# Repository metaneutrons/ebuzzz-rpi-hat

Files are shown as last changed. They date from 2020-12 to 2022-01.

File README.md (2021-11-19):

# eBuzzz adapter, an eBus to serial adapter

An eBus adapter, to convert eBus signal levels to serial level for a serial to USB converter (Works with CP2102)

# Manufacturing

Manufacturing in the `manufacturing` folder are made for JLCPCB, you may need to tweak them for other manufacturers.

# Software

The eBus protocol can be connected to with [ebusd](https://github.com/john30/ebusd). If you happen to use Home Assistant you can also connect ebusd to your Home Assistant.

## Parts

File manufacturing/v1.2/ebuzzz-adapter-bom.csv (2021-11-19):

Designator | Comment | Footprint | LCSC
C1 | 1u | Capacitor_SMD:C_0805_2012Metric | C28323
C2 | 1u | Capacitor_SMD:C_0805_2012Metric | C28323
C3 | 100n | Capacitor_SMD:C_0805_2012Metric | C49678
C4 | 1u | Capacitor_SMD:C_0805_2012Metric | C28323
C5 | 100n | Capacitor_SMD:C_0805_2012Metric | C49678
C6 | 4.7u | Capacitor_SMD:C_0805_2012Metric | C1779
D1 | RX green | LED_SMD:LED_0805_2012Metric | C2297
D2 | TX red | LED_SMD:LED_0805_2012Metric | C84256
D3 | 1SMB5924BY3G | Diode_SMD:D_SMA | C53166
D4 | ABS10 | Diode_SMD:Diode_Bridge_Diotec_ABS | C65028
D5 | power yellow | LED_SMD:LED_0805_2012Metric | C2296
D6 | 1N4148WS | Diode_SMD:D_SOD-323 | C57759
D7 | TPSP0503BAHTG | Package_TO_SOT_SMD:SOT-143 | C2682275
F1 | 1A | Fuse:Fuse_1206_3216Metric | C182308
Q1 | BC817-40 | Package_TO_SOT_SMD:SOT-23 | C181151
R3 | 1k | Resistor_SMD:R_0805_2012Metric | C17513
R4 | 470 | Resistor_SMD:R_0805_2012Metric | C17710
R5 | 2.2k | Resistor_SMD:R_0805_2012Metric | C17520
R6 | 470 | Resistor_SMD:R_0805_2012Metric | C17710
R7 | 470 | Resistor_SMD:R_0805_2012Metric | C17710
R8 | 470 | Resistor_SMD:R_0805_2012Metric | C17710
R9 | 10k | Resistor_SMD:R_0805_2012Metric | C17414
R10 | 220k | Resistor_SMD:R_0805_2012Metric | C17556
R11 | 18k | Resistor_SMD:R_0805_2012Metric | C17506
R12 | 15k | Resistor_SMD:R_0805_2012Metric | C17475
R13 | 100k | Resistor_SMD:R_0805_2012Metric | C17407
R14 | 22k | Resistor_SMD:R_0805_2012Metric | C17560
R15 | 10k | Resistor_SMD:R_0805_2012Metric | C17414
R16 | 120E | Resistor_SMD:R_0805_2012Metric | C17437
U1 | LTV-357T | Package_SO:SO-4_4.4x3.6mm_P2.54mm | C33068
U2 | LTV-357T | Package_SO:SO-4_4.4x3.6mm_P2.54mm | C33068
U3 | LM2903DT | Package_SO:SOIC-8_3.9x4.9mm_P1.27mm | C98194
U4 | LP2951-50DR | Package_SO:SOIC-8_3.9x4.9mm_P1.27mm | C109380
U5 | CP2104-F03-GM | Package_DFN_QFN:QFN-24-1EP_4x4mm_P0.5mm_EP2.6x2.6mm_ThermalVias | C430013
J4 | EBUS | Connector_Phoenix_MC:PhoenixContact_MC_1.5_2-G-3.81_1x02_P3.81mm_Horizontal | C69811
J1 | USB A | Connector_USB:USB_A_CNCTech_1001-011-01101_Horizontal | C319178

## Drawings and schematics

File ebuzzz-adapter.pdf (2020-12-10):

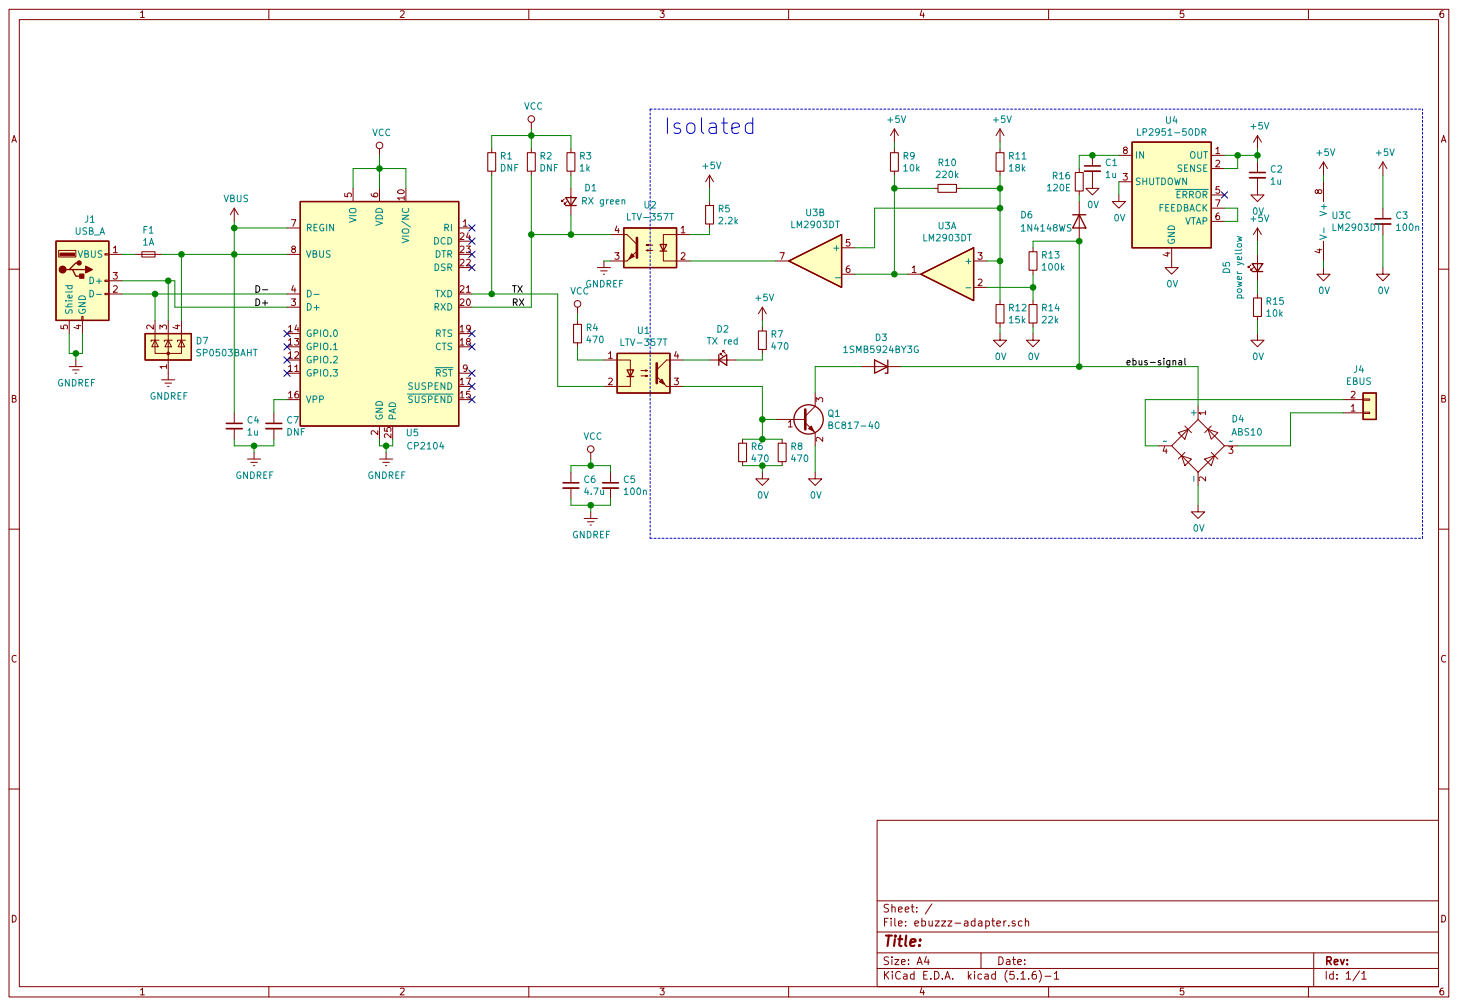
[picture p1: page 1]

4 D7SP0503BAHT OUT 1 SENSE 2 SHUTDOWN 3 GND

2 RXD 20 TXD 21 DSR 22 DTR 23 DCD 24 PAD 25 D+ 3 D- 4 VIO

File: ebuzzz-adapter.sch Sheet: /
Id: 1/1 Title:

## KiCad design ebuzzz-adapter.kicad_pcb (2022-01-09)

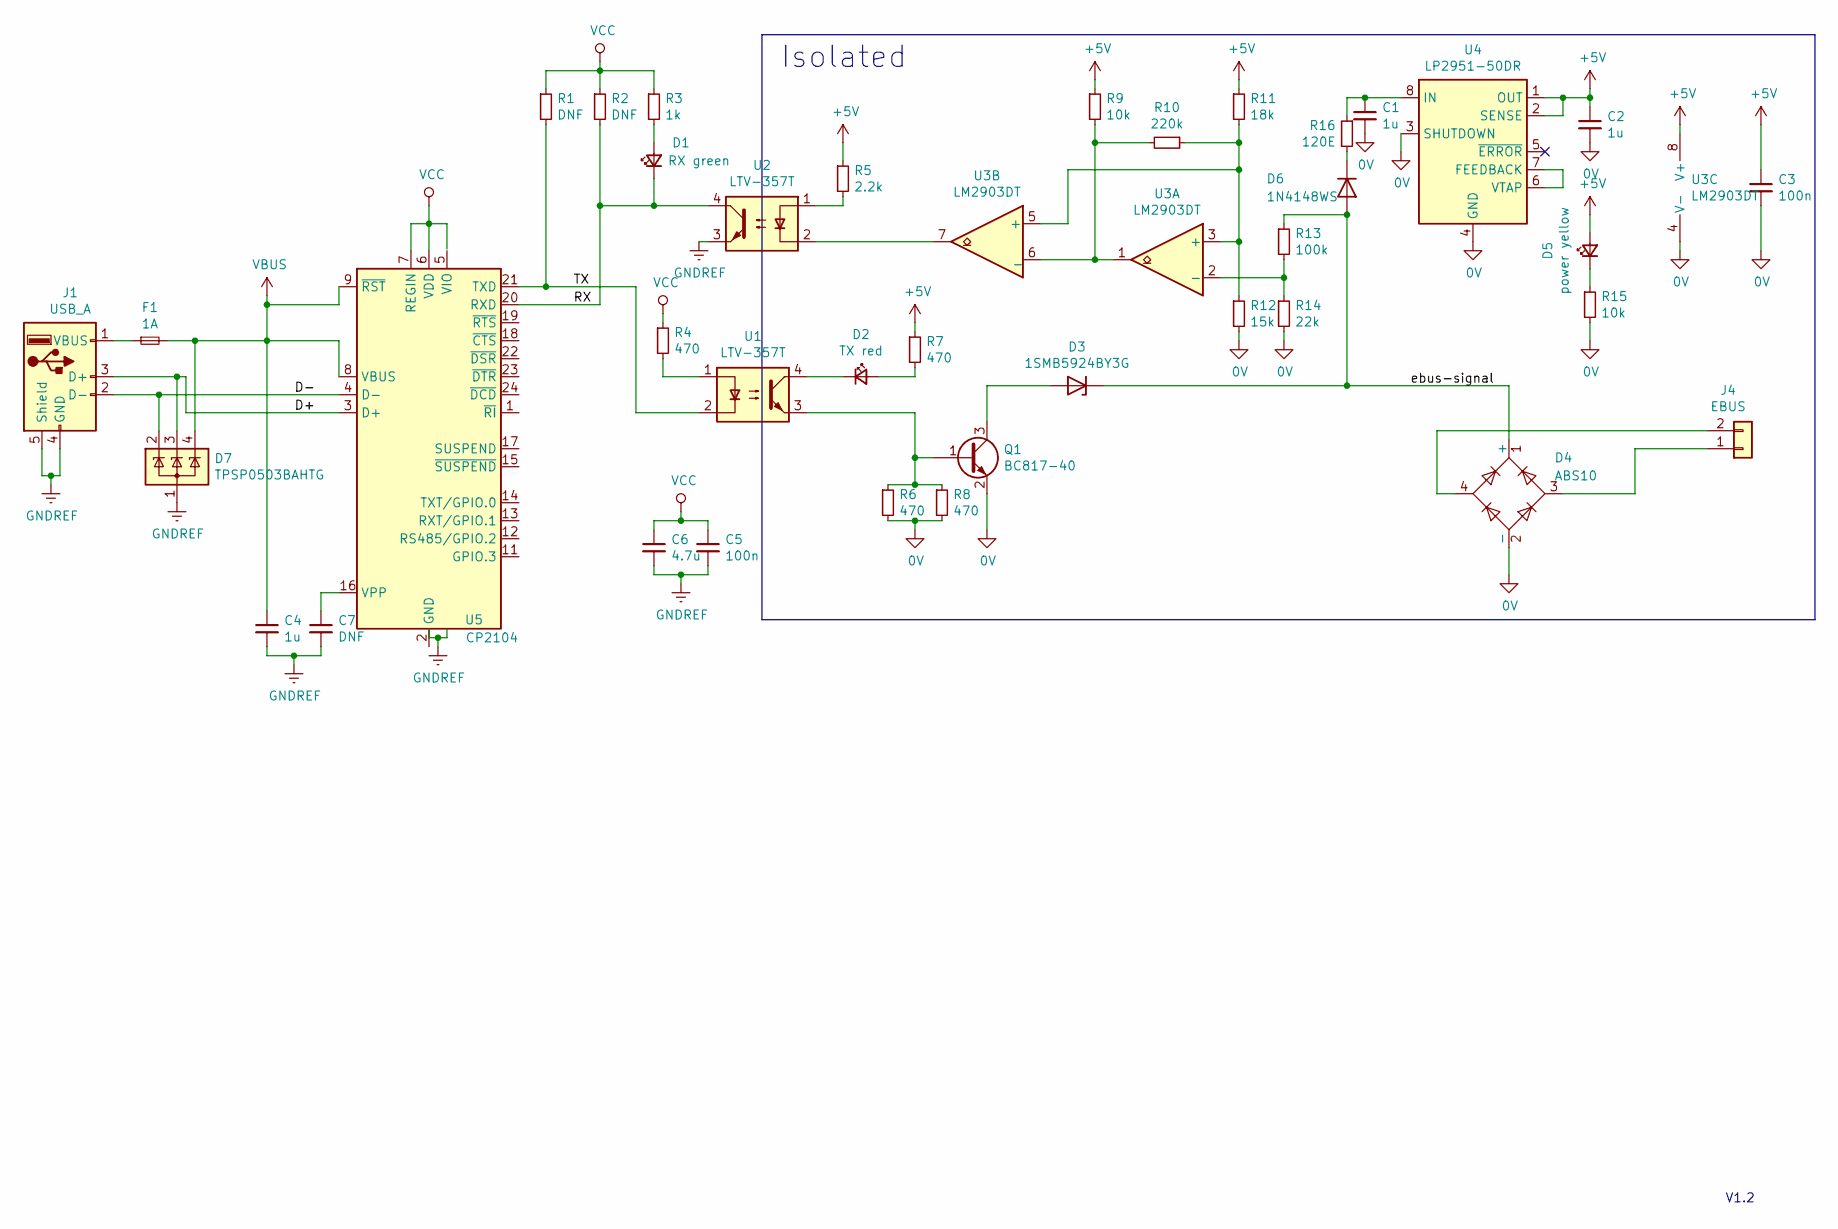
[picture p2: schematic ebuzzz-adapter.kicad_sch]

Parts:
C1, C2, C4: 1u; C_0805_2012Metric; LCSC C28323
C3, C5: 100n; C_0805_2012Metric; LCSC C49678
C6: 4.7u; C_0805_2012Metric; LCSC C1779
C7: DNF; C_0805_2012Metric
D1: RX green; LED_0805_2012Metric; LCSC C2297
D2: TX red; LED_0805_2012Metric; LCSC C84256
D3: 1SMB5924BY3G; D_SMA; Farnell 1611267
D4: ABS10; Diode_Bridge_Diotec_ABS; Farnell 3127182
D5: power yellow; LED_0805_2012Metric; LCSC C2296
D6: 1N4148WS; D_SOD-323; Farnell 2675148
D7: TPSP0503BAHTG; SOT-143; LCSC C2682275
F1: 1A; Fuse_1206_3216Metric; LCSC C182308
J1: USB_A; XKB_Connectivity_U217-041N-4BV81; LCSC C319178
J4: EBUS; PhoenixContact_MC_1,5_2-G-3.81_1x02_P3.81mm_Horizontal; LCSC C69811
Q1: BC817-40; SOT-23; Farnell 1798081
R1, R2: DNF; R_0805_2012Metric
R3: 1k; R_0805_2012Metric; LCSC C17513
R4, R6, R7, R8: 470; R_0805_2012Metric; LCSC C17710
R5: 2.2k; R_0805_2012Metric; LCSC C17520
R9, R15: 10k; R_0805_2012Metric; LCSC C17414
R10: 220k; R_0805_2012Metric; LCSC C17556
R11: 18k; R_0805_2012Metric; LCSC C17506
R12: 15k; R_0805_2012Metric; LCSC C17475
R13: 100k; R_0805_2012Metric; LCSC C17407
R14: 22k; R_0805_2012Metric; LCSC C17560
R16: 120E; R_0805_2012Metric; LCSC C17437
U1, U2: LTV-357T; SO-4_4.4x3.6mm_P2.54mm; LCSC C33068
U3: LM2903DT; SOIC-8_3.9x4.9mm_P1.27mm; Farnell 2382615
U4: LP2951-50DR; SOIC-8_3.9x4.9mm_P1.27mm; Farnell 1755065
U5: CP2104; QFN-24-1EP_4x4mm_P0.5mm_EP2.6x2.6mm_ThermalVias; LCSC C47742

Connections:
+5V: C2.1, C3.1, D5.2 (A), R5.1, R7.1, R9.1, R11.1, U3.8 (V+), U4.1 (OUT), U4.2 (SENSE)
/D+: D7.3 (K), J1.3 (D+), U5.3 (D+)
/D-: D7.2 (K), J1.2 (D-), U5.4 (D-)
/RX: D1.1 (K), R2.2, U2.4, U5.20 (RXD)
/TX: R1.2, U1.2, U5.21 (TXD)
/ebus-signal: D3.1 (K), D4.1 (+), D6.2 (A), R13.1
GND: C1.2, C2.2, C3.2, D4.2 (-), Q1.2 (E), R6.2, R8.2, R12.2, R14.2, R15.2, U3.4 (V-), U4.3 (SHUTDOWN), U4.4 (GND)
GNDREF: C4.2, C5.2, C6.2, C7.2, D7.1 (A), J1.4 (GND), J1.5 (Shield), U2.3
unnamed: C1.1, R16.1, U4.8 (IN)
unnamed: C7.1, U5.16 (VPP)
unnamed: D1.2 (A), R3.2
unnamed: D2.1 (K), U1.4
unnamed: D2.2 (A), R7.2
unnamed: D3.2 (A), Q1.3 (C)
unnamed: D4.3, J4.1
unnamed: D4.4, J4.2
unnamed: D5.1 (K), R15.1
unnamed: D6.1 (K), R16.2
unnamed: F1.1, J1.1 (VBUS)
unnamed: Q1.1 (B), R6.1, R8.1, U1.3
unnamed: R4.2, U1.1
unnamed: R5.2, U2.1
unnamed: R10.1, R11.2, R12.1, U3.3 (+), U3.5 (+)
unnamed: R9.2, R10.2, U3.1, U3.6 (_)
unnamed: R13.2, R14.1, U3.2 (-)
unnamed: U2.2, U3.7
unnamed: U4.6 (VTAP), U4.7 (FEEDBACK)
unnamed: U5.2 (GND), U5.25 (GND)
VBUS: C4.1, D7.4 (K), F1.2, U5.8 (VBUS), U5.9 (~RST)
VCC: C5.1, C6.1, R1.1, R2.1, R3.1, R4.1, U5.6 (VDD), U5.7 (REGIN)

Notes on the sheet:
Isolated
V1.2

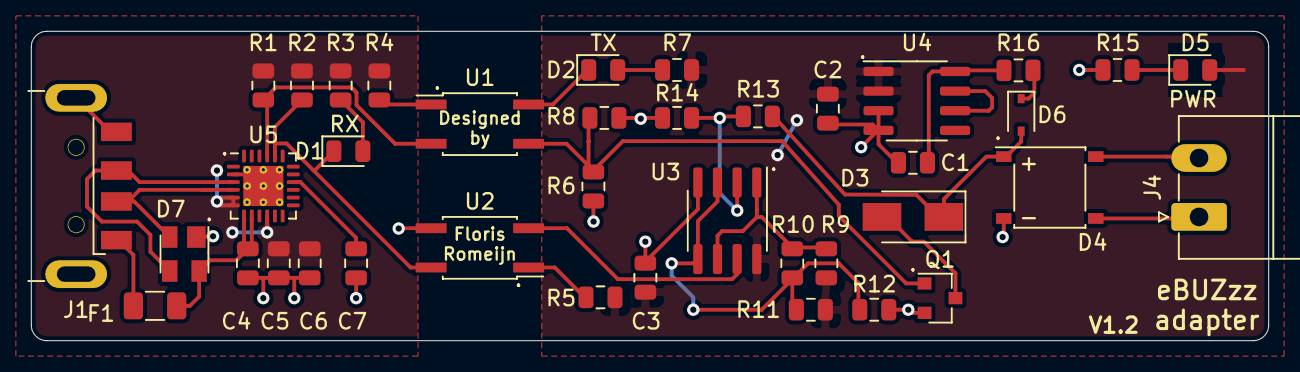
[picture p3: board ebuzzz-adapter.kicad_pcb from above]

Board: 2 copper layers, 80.0 x 20.0 mm, 39 parts (0 on the bottom side), 30 nets.

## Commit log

2019-10-25 Version 1 release (hardware tested)
    [ebuzzz-adapter-B_Cu.gbr, ebuzzz-adapter-B_Mask.gbr, ebuzzz-adapter-B_Paste.gbr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]
2020-08-11 added schematic as pdf
2020-11-12 added LCSC components (and tuned values)
    [ebuzzz-adapter.kicad_pcb, ebuzzz-adapter.sch]
2020-12-10 replace external board with onboard CP2104
    [ebuzzz-adapter-B_Cu.gbr, ebuzzz-adapter-B_Mask.gbr, ebuzzz-adapter-B_Paste.gbr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]
2021-11-19 added manufacturing files
    [ebuzzz-adapter-B_Cu.gbr, ebuzzz-adapter-B_Mask.gbr, ebuzzz-adapter-B_Paste.gbr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]
2022-01-09 Changed project to KiCad 6.0 format.
    [ebuzzz-adapter.kicad_sch, ebuzzz-adapter.sch]
2022-01-09 Fixed schematics after KiCad 6.0 upgrade.
    [ebuzzz-adapter.kicad_sch]
2022-01-09 Updated PCB.
    [ebuzzz-adapter.kicad_pcb]
